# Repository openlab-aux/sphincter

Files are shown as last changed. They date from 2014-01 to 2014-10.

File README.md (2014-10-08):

sphincter
=========
sphincter is the project name for an electronic door locking system designed at
and used by OpenLab Augsburg. This repo collects all parts of the project as 
there are
* the firmware running on the device (arduino + custom shield)
* a daemon that connects to the device via UART and exposes a HTTP API
* various client implementations
* other related files (e.g. PCB layourt for the shield, etc.)

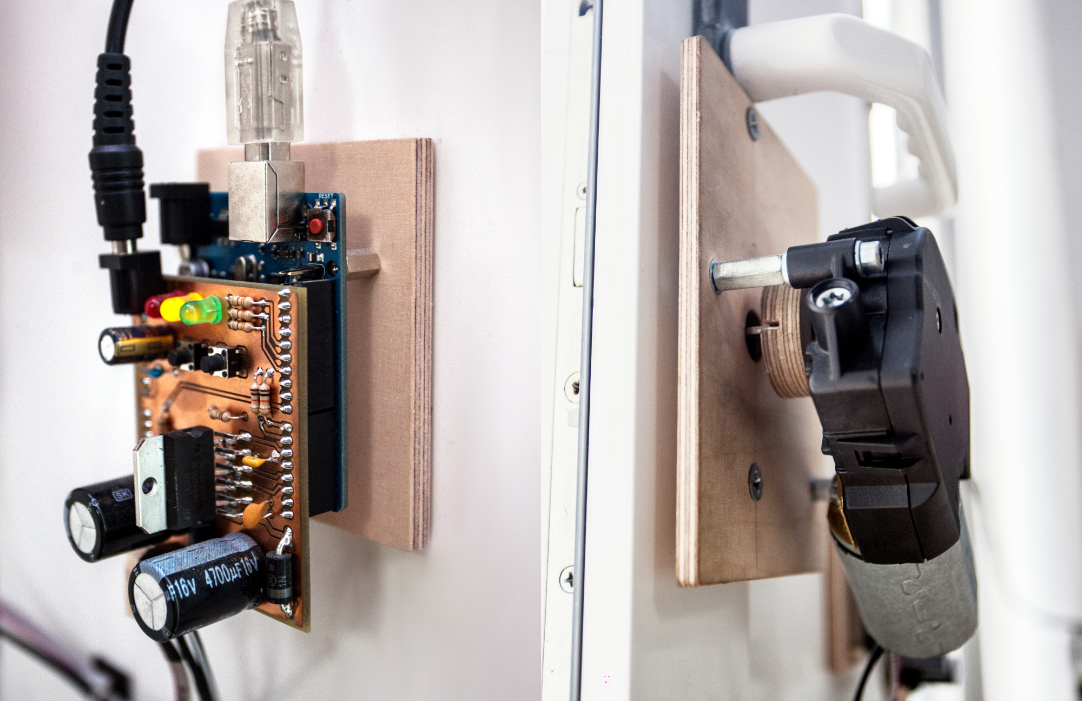
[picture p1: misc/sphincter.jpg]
sphincter installed


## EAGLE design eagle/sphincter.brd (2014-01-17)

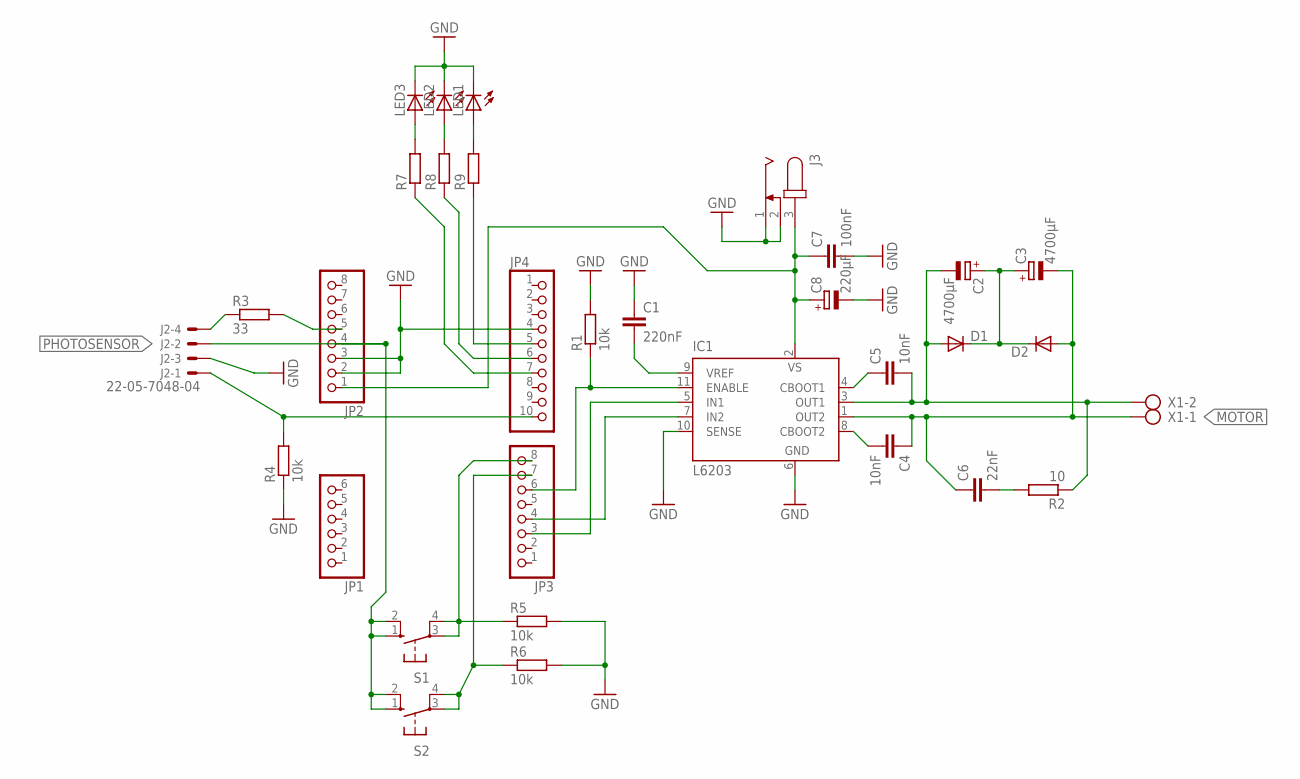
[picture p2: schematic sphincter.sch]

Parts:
C1: 220nF; C050-024X044
C2, C3: 4700µF; E7,5-16
C4, C5: 10nF; C025-025X050
C6: 22nF; C050-024X044
C7: 100nF; C050-024X044
C8: 220µF; E3,5-8
D1, D2: DIODE-DO27-15; DO27-15
IC1: L6203; MULTIWATT-11
J2: 22-05-7048-04; 7395-04
J3: JACK-PLUG0; SPC4077
JP1: PINHD-1X6; 1X06
JP2, JP3: PINHD-1X8; 1X08
JP4: PINHD-1X10; 1X10
LED1, LED2, LED3: LED5MM
R1, R4, R5, R6: 10k; 0207/10
R2: 10; 0207/10
R3: 33; 0207/10
R7, R8, R9: R-EU_0207/10; 0207/10
S1, S2: 10-XX; B3F-10XX
X1: AK500/2

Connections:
5V_DETECTOR: JP2.5, R3.2
GND: C1.1, C7.2, C8.-, IC1.6 (GND), IC1.10 (SENSE), J2.3, J3.1, J3.2, JP2.2, JP2.3, JP4.4, LED1.K (C), LED2.K (C), LED3.K (C), R1.2, R4.1, R5.2, R6.2
MOTOR: C3.-, C4.1, C6.1, D2.A, IC1.1 (OUT2), X1.1
unnamed: C1.2, IC1.9 (VREF)
unnamed: IC1.7 (IN2), JP3.4
unnamed: IC1.5 (IN1), JP3.3
unnamed: IC1.11 (ENABLE), JP3.6, R1.1
unnamed: C7.1, C8.+, IC1.2 (VS), J3.3, JP2.1
unnamed: C2.+, C3.+, D1.C, D2.C
unnamed: C4.2, IC1.8 (CBOOT2)
unnamed: C5.1, IC1.4 (CBOOT1)
unnamed: C6.2, R2.2
unnamed: C2.-, C5.2, D1.A, IC1.3 (OUT1), R2.1, X1.2
unnamed: JP3.8, R5.1, S1.3, S1.4 (P1)
unnamed: JP3.7, R6.1, S2.3, S2.4 (P1)
unnamed: JP4.5, R9.1
unnamed: LED3.A, R7.2
unnamed: LED2.A, R8.2
unnamed: LED1.A, R9.2
unnamed: JP4.6, R8.1
unnamed: JP4.7, R7.1
unnamed: J2.4, R3.1
PHOTOSENSOR: J2.2, JP2.4, S1.1 (S), S1.2 (S1), S2.1 (S), S2.2 (S1)
TO_ARDUINO: J2.1, JP4.10, R4.2

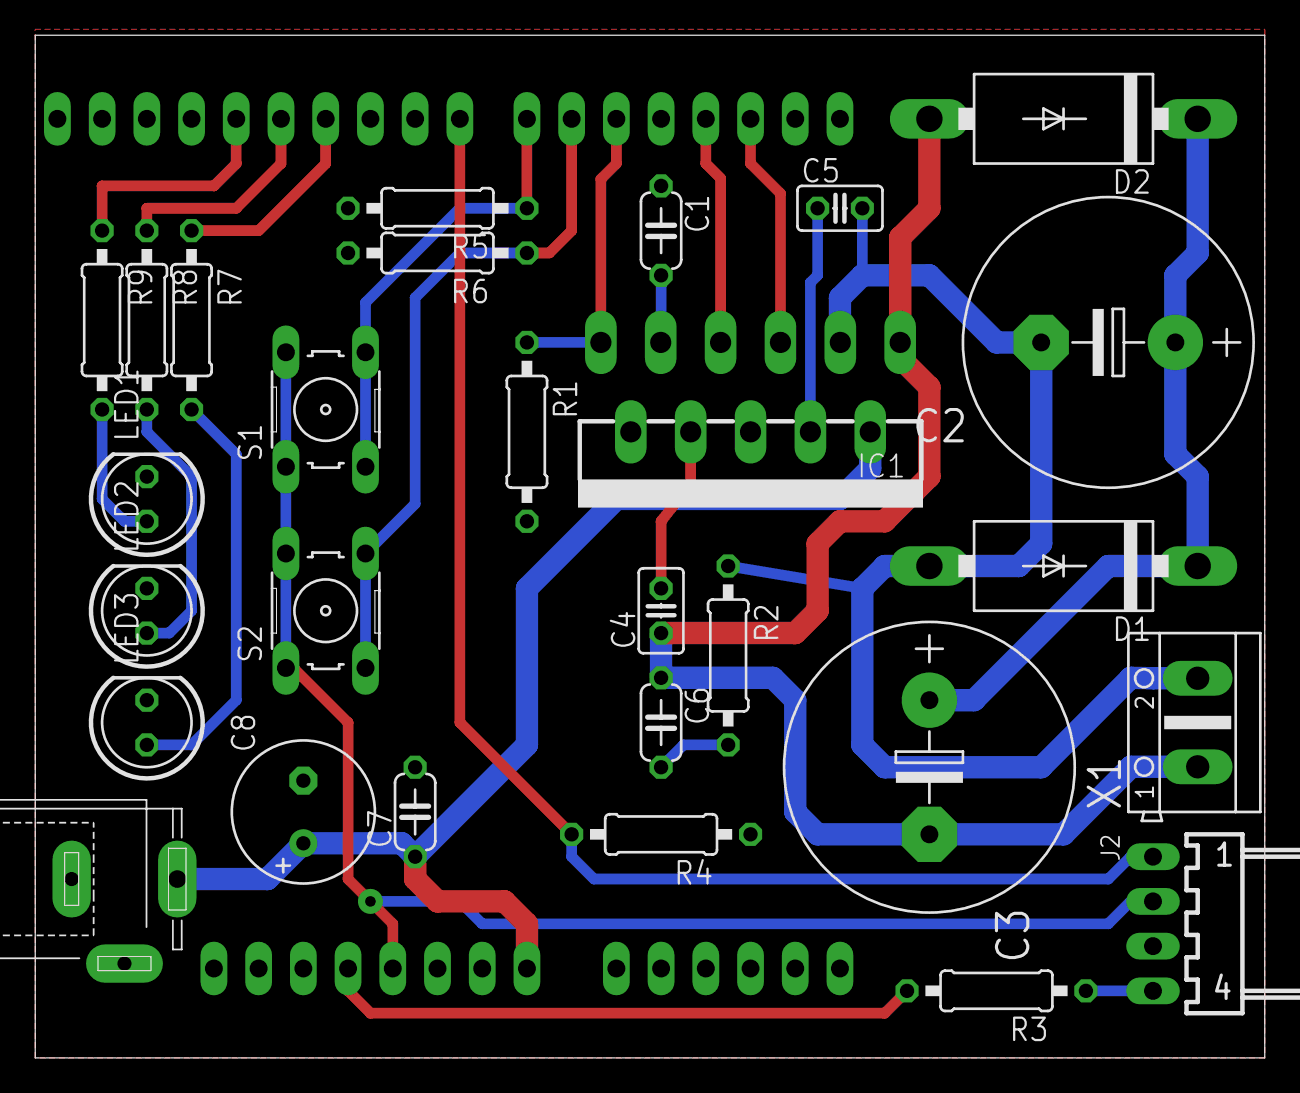
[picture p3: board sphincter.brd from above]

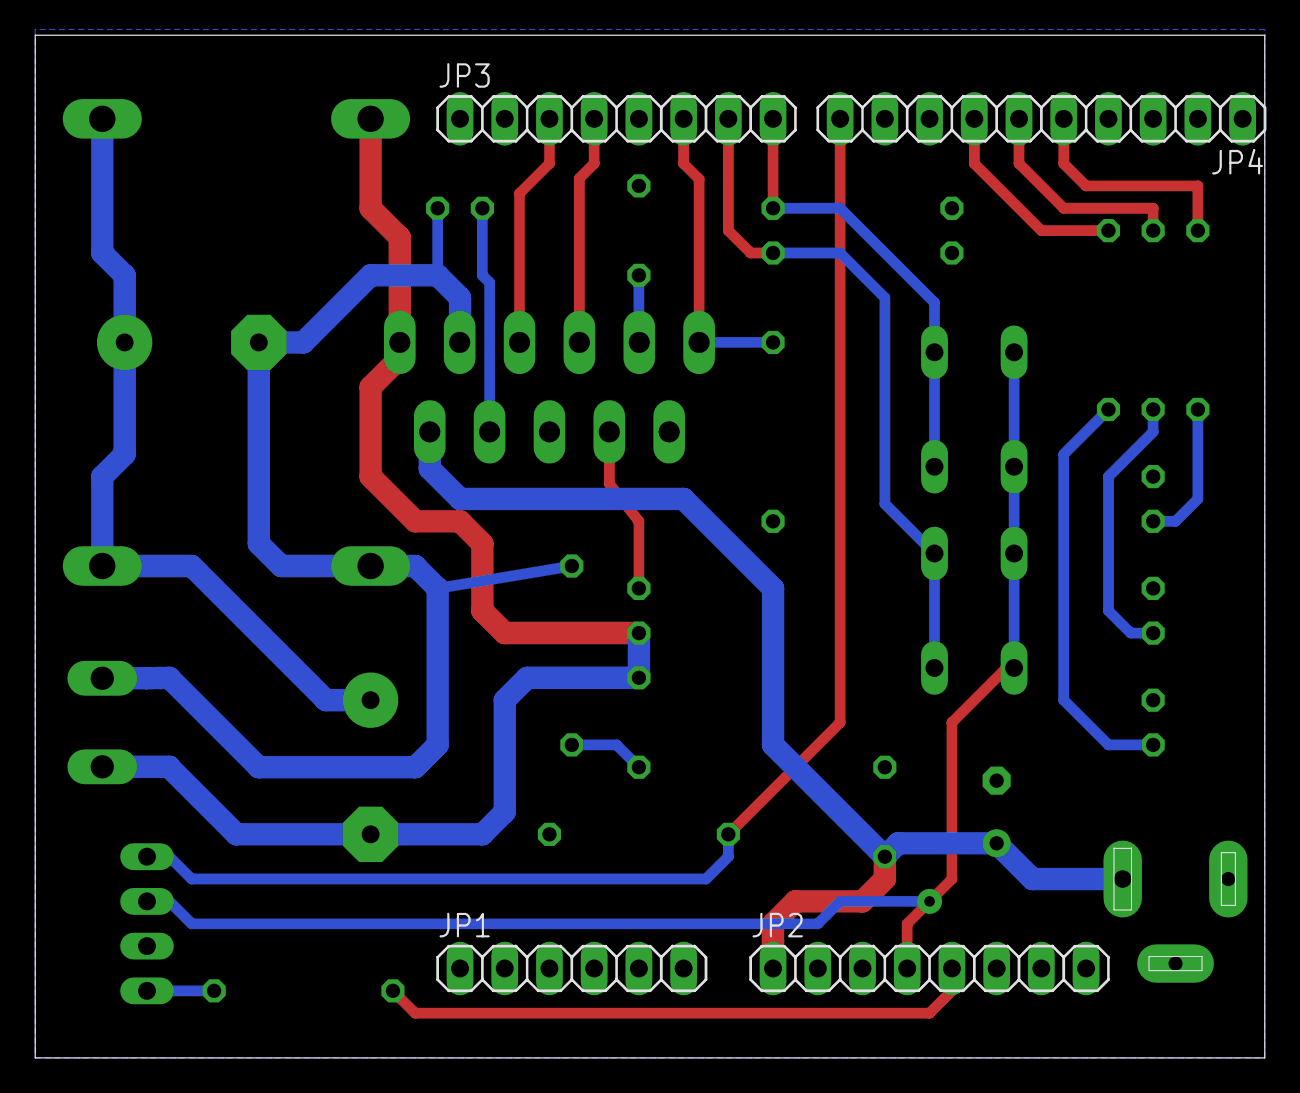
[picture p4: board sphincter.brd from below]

Board: 2 copper layers, 69.8 x 58.1 mm, 32 parts (4 on the bottom side), 24 nets.

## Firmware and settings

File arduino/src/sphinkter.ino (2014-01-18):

// driver pins
#define OPEN  3
#define CLOSE 2
#define PWM   5

// photo sensor pin
#define PHOTOSENS  8

// motor speed 0-255 (PWM)
#define FAST 255 
#define SLOW 50

// lock positions (photo sensor steps)
#define LOCK_CLOSE  0
#define LOCK_OPEN   9
#define DOOR_OPEN   10

// delay after motor has stopped to avoid misinterpretations
#define PS_DELAY 50

// LEDs
#define LED_R 11
#define LED_Y 12
#define LED_G 13

// Buttons
#define BUTTON_CLOSE 6
#define BUTTON_OPEN 7


int position;


void stateChanged() {

    // the state of sphinkter has changed. Update LEDs
    // and submit state over serial connection

    digitalWrite(LED_R, LOW);
    digitalWrite(LED_Y, LOW);  
    digitalWrite(LED_G, LOW);
    
    switch(position) {
        
        case LOCK_CLOSE: {
                         digitalWrite(LED_R, HIGH);
                         Serial.println("Door locked");
                         break;
                     }

        case LOCK_OPEN:  {
                         digitalWrite(LED_Y, HIGH); 
                         Serial.println("Door unlocked");
                         break;
                     }

        case DOOR_OPEN:  {
                         digitalWrite(LED_G, HIGH); 
                         Serial.println("Door open");
                         break;
                     }
  
  }
  
}


void searchRef() {

    int counter = 0;
    boolean was_interrupted = false;

    digitalWrite(LED_R, HIGH);
    digitalWrite(LED_Y, HIGH);  
    digitalWrite(LED_G, HIGH);
 
    Serial.println("Searching reference point...");

    analogWrite(PWM, SLOW); // speed (PWM)
    digitalWrite(CLOSE, HIGH); // motor power on
  
  
    do {
        
        delay(15); // don´t count at cpu speed
   
        // photo sensor becomes interrupted
        if( !digitalRead(PHOTOSENS) && !was_interrupted ) {

            counter = 0;
            was_interrupted = true;

        }
        // photo sensor becomes free
        else if( digitalRead(PHOTOSENS) && was_interrupted ) {
            
            counter = 0;
            was_interrupted = false;

        }
        
        counter ++;
        
    } while( counter < 50 );
      
 
    digitalWrite(CLOSE, LOW); // motor power off
    
    delay(PS_DELAY);
    
    // turn back to first pad (= position 0)
    while( digitalRead(PHOTOSENS) ) { digitalWrite(OPEN, HIGH); }
    digitalWrite(OPEN, LOW);
    
    position = 0;
    stateChanged();

}


void turnLock(int new_position) {

    if( new_position == position 
            || new_position < LOCK_CLOSE 
            || new_position > DOOR_OPEN ) return;

    int step;
    int direction;
    boolean was_interrupted = false;
    
    // open lock
    if( new_position > position ) {        
        
        step =  1; // increment position
        direction = OPEN;
        
    }
    // close lock 
    else if( new_position < position ) {       

        step = -1; // decrement position
        direction = CLOSE;

    }

    analogWrite(PWM, FAST); // speed (PWM)
    digitalWrite(direction, HIGH); // motor power on

    // wait for photo sensor to become free
    while( !digitalRead(PHOTOSENS) );
    delay(PS_DELAY);

    do {
   
        // photo sensor becomes interrupted
        if( !digitalRead(PHOTOSENS) && !was_interrupted ) {

            position += step;
            was_interrupted = true;

        }
        // photo sensor becomes free
        else if( digitalRead(PHOTOSENS) && was_interrupted ) {
            
            was_interrupted = false;

        }
        
    } while( position != new_position );

    digitalWrite(direction, LOW); // motor power off

    delay(PS_DELAY);
    
    // if necessary turn back to correct position
    if( direction == OPEN ) {

        while( digitalRead(PHOTOSENS) ) { digitalWrite(CLOSE, HIGH); } 
        digitalWrite(CLOSE, LOW);

    }
    else if( direction == CLOSE ) {
        
        while( digitalRead(PHOTOSENS) ) { digitalWrite(OPEN, HIGH); }
        digitalWrite(OPEN, LOW);

    }


    stateChanged();

    // turn back after opened the door
    if( new_position == DOOR_OPEN ) {
        delay(300); 
        turnLock(LOCK_OPEN);
    }

}



void processButtonEvents() {
  
    static boolean open_was_pressed = false;
    static boolean close_was_pressed = false;

    if( digitalRead(BUTTON_OPEN) && digitalRead(BUTTON_CLOSE) ) {

        searchRef();
        open_was_pressed = false;
        close_was_pressed = false;

    }
    else if( digitalRead(BUTTON_OPEN ))  open_was_pressed = true; 
    else if( digitalRead(BUTTON_CLOSE))  close_was_pressed = true; 
    else if( !digitalRead(BUTTON_OPEN) && open_was_pressed ) {
        
        open_was_pressed = false;
        turnLock(DOOR_OPEN);
         
    }
    else if( !digitalRead(BUTTON_CLOSE) && close_was_pressed ) {
        
        close_was_pressed = false;
        turnLock(LOCK_CLOSE);

    }
    
}


void processSerialEvents() {
    
    char incomingByte;
    
    // check if there was data sent
    if (Serial.available() > 0) {
            // read the incoming byte:
            incomingByte = Serial.read();

            switch(incomingByte) {
                case 'o': turnLock(DOOR_OPEN); break;
                case 'c': turnLock(LOCK_CLOSE); break;
                case 'r': searchRef(); break;
            }
    }

}


void setup()  { 

    // initialize pins
    pinMode(LED_R, OUTPUT);
    pinMode(LED_Y, OUTPUT);
    pinMode(LED_G, OUTPUT);
    pinMode(OPEN, OUTPUT);     
    pinMode(CLOSE, OUTPUT);
    pinMode(PHOTOSENS, INPUT);

    // serial debugging
    Serial.begin(9600);
    //Serial.println("************************************************");
    //Serial.println("*                                              *");
    //Serial.println("*     Welcome to fu**ing awesome Sphinkter     *");
    //Serial.println("*                                              *");
    //Serial.println("*        send 'o', 'c' to open / close         *");
    //Serial.println("*        and 'r' to reset positioning          *");
    //Serial.println("*                                              *");
    //Serial.println("************************************************");
    
    Serial.println(" welcome to fucking awesome sphinkter!");
    Serial.println("");        
    Serial.println("  /     \\             \\            /    \\");
    Serial.println(" |       |             \\          |      |");      
    Serial.println(" |       `.             |         |       :");
    Serial.println(" `        |             |        \\|       |");     
    Serial.println("  \\       | /       /  \\\\\\   --__ \\\\       :");
    Serial.println("   \\      \\/   _--~~          ~--__| \\     |");      
    Serial.println("    \\      \\_-~                    ~-_\\    |");
    Serial.println("     \\_     \\        _.--------.______\\|   |");    
    Serial.println("       \\     \\______// _ ___ _ (_(__>  \\   |");
    Serial.println("        \\   .  C ___)  ______ (_(____>  |  /");    
    Serial.println("        /\\ |   C ____)/      \\ (_____>  |_/");
    Serial.println("       / /\\|   C_____)       |  (___>   /  \\");    
    Serial.println("      |   (   _C_____)\\______/  // _/ /     \\");
    Serial.println("      |    \\  |__   \\\\_________// (__/       |");  
    Serial.println("     | \\    \\____)   `----   --'             |");  
    Serial.println("     |  \\_          ___\\       /_          _/ |"); 
    Serial.println("    |              /    |     |  \\            |"); 
    Serial.println("    |             |    /       \\  \\           |"); 
    Serial.println("    |          / /    |         |  \\           |");
    Serial.println("    |         / /      \\__/\\___/    |          |");
    Serial.println("   |           /        |    |       |         |");
    Serial.println("   |          |         |    |       |         |");
    Serial.println("");
    Serial.println("      send 'o', 'c' to open / close");
    Serial.println("        and 'r' to reset positioning");
    Serial.println("");


    searchRef();
       
}


void loop()  { 
    
    processButtonEvents();
    
    processSerialEvents(); 

}

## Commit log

2014-01-12 another fix to avoid miscounting
    [sphinkter.ino]
2014-01-12 bad idea to delay before braking the motor
2014-01-17 changes to work with sphinkter board
    removed ethernet shield support
    added primitive serial communication
    implemented buttons and LEDs
    changed arduino pins
    other minor changes
2014-01-17 added eagle schematics and board layout
    [sphinkter.brd, sphinkter.sch]
2014-01-17 reenabled reference drive on reset
    [sphinkter.ino]
2014-01-20 add folder for arduino stuff
2014-01-20 changed 'shinkter' to 'sphincter'
    [sphincter.brd, sphincter.sch]
2014-01-20 pretty printing
2014-01-21 added udev rule
    assign arduinos serial device to a fixed symlink
2014-01-21 changed rule to match the sphincter arduino board
2014-01-22 serial device as created by the udev rule
2014-02-20 use correct device
2014-02-25 Added the current date to the generated e-mail.
2014-08-20 basic http server that relays state from serial
2014-08-30 adds TimerOne library
2014-09-03 func to toggle LEDs
2014-09-03 new button handling, fixes #8
2014-09-28 daemon: set state "BUSY" in any case
    to avoid having more than one request in the small gap until
    sphincter returns "BUSY"
